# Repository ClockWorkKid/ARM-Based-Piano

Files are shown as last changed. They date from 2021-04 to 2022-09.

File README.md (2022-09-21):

# ARM-Based-Piano
STM32 based digital piano project for EEE416 Microprocessor and Embedded Systems Laboratory

Demonstration video <a href="https://youtu.be/l-ic4qlintA">link</a>

[](https://www.youtube.com/watch?v=l-ic4qlintA "Now in Android: 55")

## Contents
- [Repository Overview](#repository-overview)
- [Materials Used](#materials-used)
- [Softwares Used](#softwares-used)
- [Useful Links](#useful-links)
- [Working Procedure](#working-procedure)
- [Resampling Implementation in MATLAB](#resampling-implementation-in-matlab)
- [Resampling Implementation in C](#resampling-implementation-in-c)
- [DAC Simulation and Design Using Proteus](#dac-simulation-and-design-using-proteus)
- [Keyboard Interfacing Using Arduino DUE and Interrupt](#keyboard-interfacing-using-arduino-due-and-interrupt)
- [STM32 Code](#stm32-code)
- [Team](#team)

## Repository Overview
The repository directories include several folders for each component of the project. The purpose of each of the folders is listed here:

- **Solidworks Design** contains hardware design files that was used to build the PVC structure.
 
- **Arduino Due** folder contains the codes for the keyboard interfacing part of the piano. This board was used to read inputs from the 36 keys of the piano and send the keypress information to the STM32 board.

- **Matlab Simulation** folder contains resampling implementation and test codes for matlab. This was the first test for audio tone synthesis from a single note. Afterwards this code was ported to C.

- **C simulation** folder contains C-codes for audio resampling implementation which was directly used in the STM32 project code.

- **STM32** is the STM32CubeIDE project folder where the final implementation of SD-card reading, keyboard interfacing, audio synthesis and playback was implemented.

## Materials Used

- STM32F746 Discovery Board
- Arduino Due Board
- Arduino Uno Proto Shield
- Screws (for key contact + body)
- Female-Female jumpers (A lot!)
- 26 AWG wires (connects screws with circuit board)
- Aluminium foil (positive rail)
- 3.5mm headphone jack female
- Veroboard, soldering tools
- AWEI Y220 speaker with auxiliary cable
- Micro SD Card

## Softwares Used

- STM32CubeIDE
- Arduino IDE
- Proteus
- Matlab
- Codeblocks

## Useful Links

- <a href="https://www.youtube.com/playlist?list=PLc2rvfiptPSR0bzPjEsg5zmj0jvYMZLbV">A youtube playlist</a> containing useful videos for the STM32F746 Discovery Board

## Working Procedure

### Audio note synthesis from a single base note

A sample note of high resolution (44.1 KHz, 24 bit sample size) was downloaded. (The notes can be found at http://theremin.music.uiowa.edu/MISpiano.html). First we trimmed the note, and resampled it using MATLAB to see if the new note satisfies the frequency requirements of the target note. Then the resample function of MATLAB was manually written using resample theory (upsampling, interpolation using sinc function, downsampling). This code also generated similar notes, implying the correct operation of resample function. Finally the resampling function was ported to C code for using with STM32 board

<p align="center">
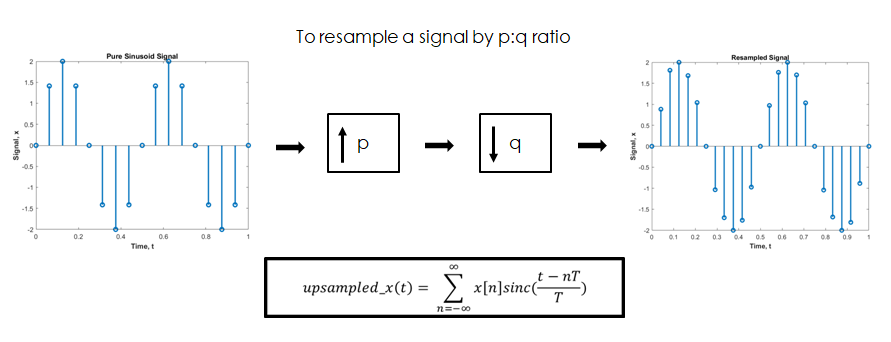
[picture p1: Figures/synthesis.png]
Note Synthesis
  
</p>

### Keyboard interfacing with a STM32 board

The designed hardware keyboard has 36 keys in total (3 octaves) and the keys are all connected to the Arduino DUE board (the STM32 discovery board did not have enough pins available as most of them were connected internally to other peripherals). Arduino DUE board reads the keypresses in polling mode with debouncing enabled. When a keypress is detected, DUE board sents an interrupt to the STM32 board along with the ID of the corresponding key being pressed.

### Note playback from STM32 board

The 36 piano notes are saved inside a micro SD card in binary format (8 kHz sampling rate, 8 bit resolution) and when a keypress is detected, the STM32 Discovery board reads the corresponding binary file, sends the audio samples to a buffer, and using the DAC circuit, these sample values are sent to the speaker device.

<p align="center">
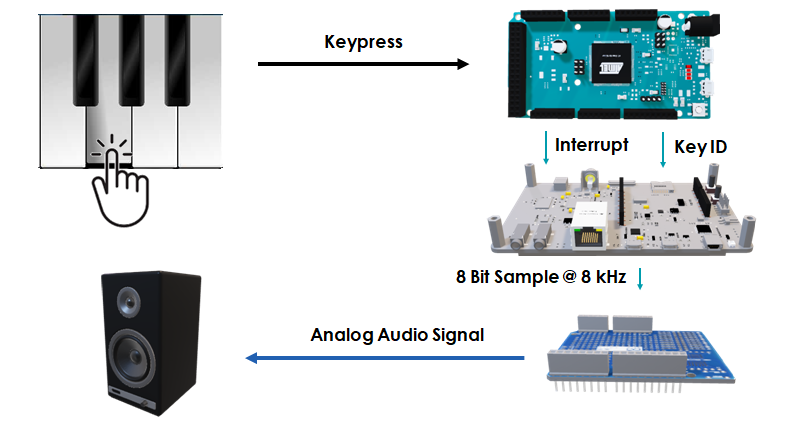
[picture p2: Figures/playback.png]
Note Playback
  
</p>

## Resampling Implementation in MATLAB
### Fundamentals:

In a conventional piano, there are 88 keys (A0-C8) that all produce tones of different frequency. These keys are divided into 8 octaves. Each octave has 12 steps.

An example of an octave is as follows: A0, A0#, B0, C1, C1#, D1, D1#, E1, F1, F1#, G1, G1#

Our task is to take one of these tones as our fundamental audio which we will then use to resample and generate the other audio tones of different frequencies.

In our project, we have decided to take A2 as our fundamental tone. It has a frequency of 110 Hz. Now, the other audio tones are related to the base frequency through the following equation:

f(n)=2^((n-25)/12)×110 Hz

Here, n represents the number of the piano key. The number of the piano keys are also predetermined. The lowest frequency tone A0 corresponds to key 1 and the highest frequency tone C8 corresponds to key 88. Our base audio A2 has key 25. Through the relation in equation (1), we can determine the resampling ratio that is needed to generate any particular tone from A2.

### Resampling on sinusoidal signal:

Before we move on to how resampling is performed on the raw audio, it is easier to demonstrate the theory of resampling using a short pure sinusoid signal. Let us assume, we have a pure sinusoid of frequency 2 Hz and it has been sampled at a rate of 16 Hz. So the sampled signal looks as the following:

<p align="center">
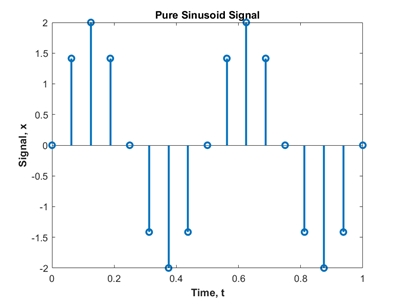
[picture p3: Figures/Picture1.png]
Sampled Signal
  
</p>

Our goal is to resample it at a ratio of 3:2. In order to do this, we need to,
Upsample the signal by 3. That means, (3-1) = 2 new samples will be inserted between every successive sample. Then downsample the signal by 2. That means, one sample is kept and the next is discarded.

### Upsampling

To Upsample the signal, we use the following equation of Sinc interpolation, 

<p align="center">
  
</p>

Here, x[n] is the original signal. It has a sampling period, T. We need to interpolate between two successive samples of ‘x’ and find out the extra sample values in between. The ‘t’ essentially represents the upsampled time axis. Now, we will visualize what’s happening with animation.

<p align="center">
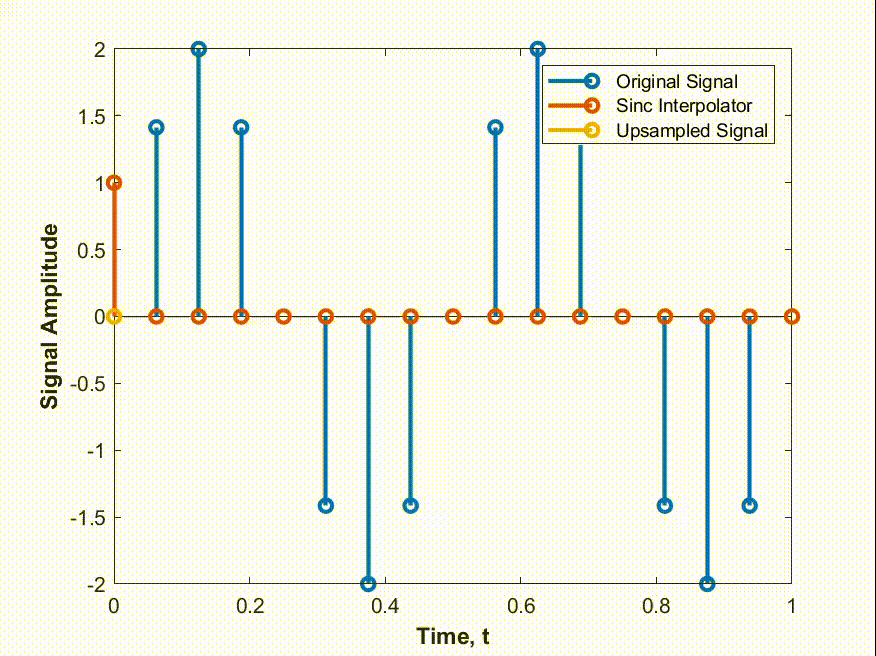
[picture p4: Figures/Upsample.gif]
Upsampled Signal
  
</p>

In this animation, the original signal is being upsampled by a factor of 3. So, 2 new samples are interpolated between any two successive samples. This interpolation is done through the use of a sinc function. As you can see, the sinc does a weighted averaging of the original signal at the new sampling instances. The amplitude of the upsampled signal at the original sampling instances remains the same as the sinc becomes zero everywhere else but the sampling instance.

#### Code Snippet: 

``` MATLAB
function [upsampled_x_raw, upsampled_t] = upsample(x,t,upsampling_factor)

T = t(2)-t(1);
fs = 1/T;

fs_upsample = upsampling_factor*fs;
upsampled_t = 0:1/fs_upsample:((length(x)-1)/fs);
upsampled_x_raw = zeros(length(upsampled_t), 1);

a = zeros(length(t),1);

for i = 1:length(upsampled_t)
    a(:,1) = upsampled_t(i);
    b = a - t';
    d = sinc(b/T);
    upsampled_x_raw(i) = sum(x'.*d);
end

end

```
### Downsampling: 
Downsampling refers to removing samples at a periodic interval from the upsampled signal. In the animation, we can see the that every alternate sample is being removed from the upsampled signal. The result is a signal downsampled by a factor of 2. 

<p align="center">
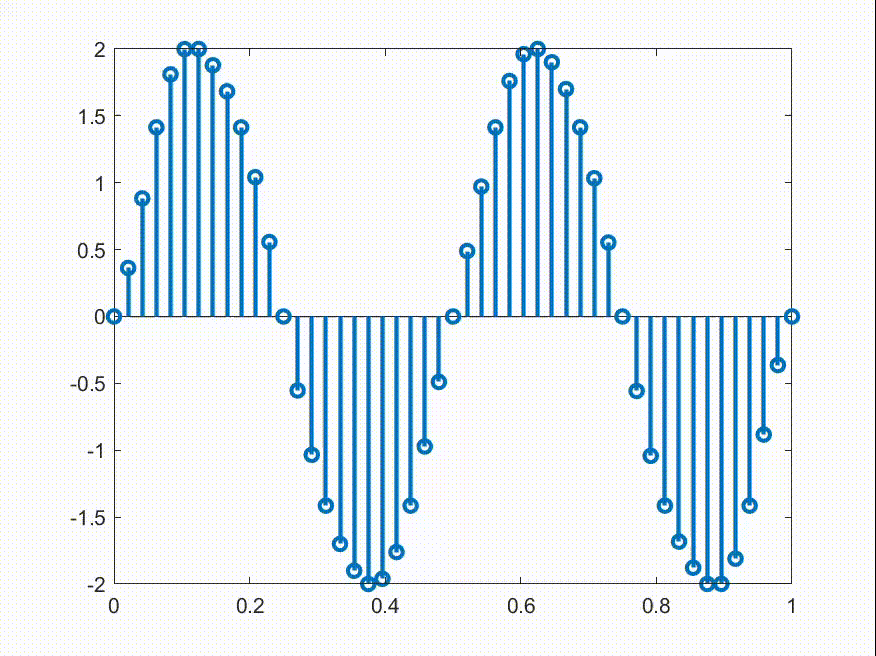
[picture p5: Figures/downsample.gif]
Downsampled Signal
  
</p>

#### Code Snippet:
``` C
function [downsampled_x, downsampled_t] = downsample(x,t,downsampling_factor)

T = t(2)-t(1);
fs = 1/T;

downsampled_x = zeros(round((1/downsampling_factor)*length(x)),1);
fs_downsample = fs/downsampling_factor;
downsampled_t = 0:1/fs_downsample:((length(x)-1)/fs);

for i=1:length(downsampled_x)
    downsampled_x(i) = x(i*downsampling_factor - downsampling_factor + 1);
end

end

```
### Main Code:
``` MATLAB
clear all, close all, clc

%% Load Audio
% http://theremin.music.uiowa.edu/MISpiano.html
[A2, fs] = audioread("Piano.pp.A2.aiff");
A2 = A2(1:100000, :)*10; 
t = 0:1/fs:((length(A2)-1)/fs);

%% Upsampling and filtering
upsampling_factor = 2;
[upsampled_A2, upsampled_t] = upsample(A2(:,1)',t,upsampling_factor);

%% Downsampling
downsampling_factor = 1;
[A1_M, downsampled_t] = downsample(upsampled_A2, upsampled_t, downsampling_factor);

```
## Resampling Implementation in C
Now that we have an understanding of how to implement resampling in software, we need to make our code hardware compatible. To do this, we rewrite the same functions in C. The underlying principles are the same, so we are only going to show the code snippets.
### Code Snippets:
#### Upsampling: 

``` C
void upsample()
{
    int k,j;
    double t_step,fs_u,b,sum;
    t_step = 1/fs;
    fs_u = fs*u;
    for(k=0; k<up_SIZE; k++)
    {
        b = (double)k/fs_u;
        sum = 0;
        for (j=0;j<SIZE;j++)
        {
          a[j] = (b/t_step) - j;
            if (a[j]!=0)           
                a[j] = sin(pi*a[j])/(pi*a[j]);
            else
                a[j] = 1;
            sum = sum + a[j]*x[j];
        }       up_x[k] = sum;
    }
}
```
#### Downsampling:
``` C
void downsample()
{
    int k;
    for(k = 0; k<down_SIZE; k++)
    {
        down_x[k] = up_x[d*k];
    }
}

```

However, there are some challenges in hardware implementation. These are listed as follows:
- Since any two consecutive audio tones are related to each other by a factor of 2^(1/12), so we have to approximate this irrational number to an integer ratio. But there are practical limitations on this ratio. Because we have limited memory on our microcontroller board, we cannot upsample the signal to any arbitrary ratio.
- Since our audio signal is large (64000 samples), we cannot perform resampling on the total signal at once because the upsampled signal becomes too large and does not fit into memory

### Solution to memory limitations:

The audio signal is broken up to equal sized slices. Resampling is performed on one slice at a time.

The signal slice after downsampling is then written to the external memory card

<p align="center">
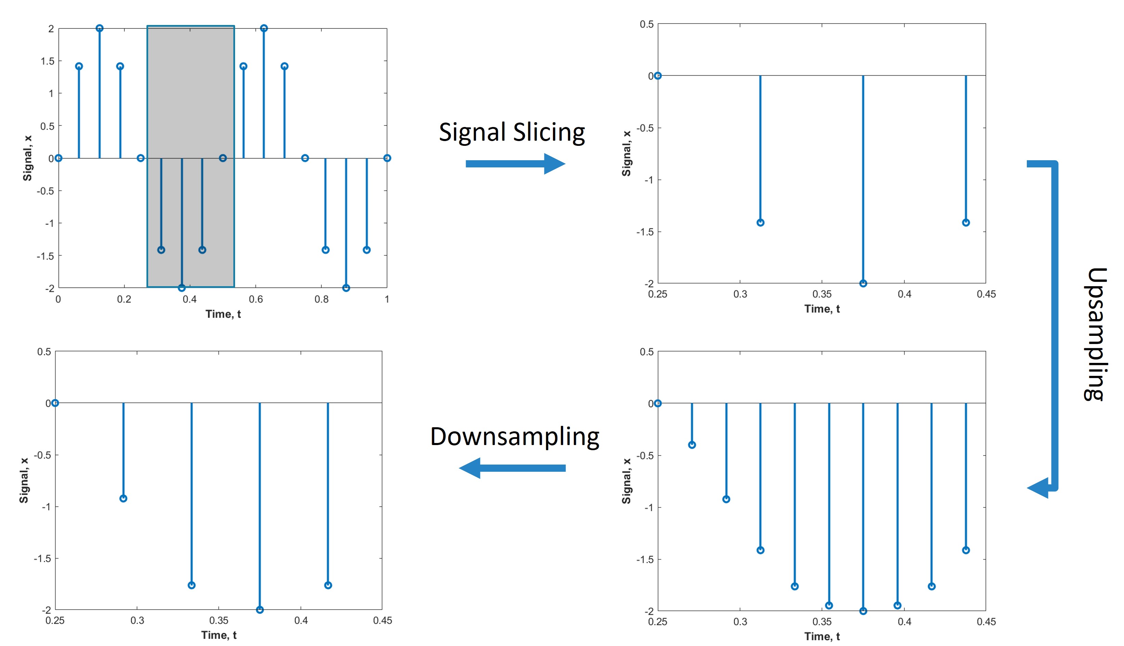
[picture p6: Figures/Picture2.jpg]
Resampling summary
  
</p>

#### Code Snippet for Signal Slicing:
``` C
for(i=0; i<num_iter; i++)
{
    /*get 1000 values and load into x*/
    for (j=0; j<SIZE; j++)
    {
       //convert integer to float
       float_value = (double)((DATA_BUFFER[i*SIZE + j] - 127));
       x[j] = float_value/128;
    }

    upsample();
    downsample();

    //convert to integer again
    for (j=0; j<down_SIZE; j++)
    {
      FINAL_BUFFER[j] = (uint8_t)(down_x[j]*128.0 + 127.0);
    }

}
```

### Parameters and Error Minimization:
- The highest Upsampling ratio we have used is 25. 
- The slice length is set to 800
There is a trade-off between these two parameters. If we increase the slice length, then the highest permissible ratio for Upsampling will decrease to meet memory requirements and vice-versa.
Between the end of any slice and the beginning of the next slice, the extra samples for Upsampling are not inserted. This is a source of error. Since we keeping the slice length to a sufficiently large number, this error is not significant.  

## Keyboard Interfacing Using Arduino DUE Interrupt

### Arduino DUE Connection with Keyboard Hardware

A hardware keyboard was prepared using 5mm PVC sheet. Each of the piano keys has a screw through them, and on the other side of each screw is a wire connecting it to a circuit board.
<p align="center">
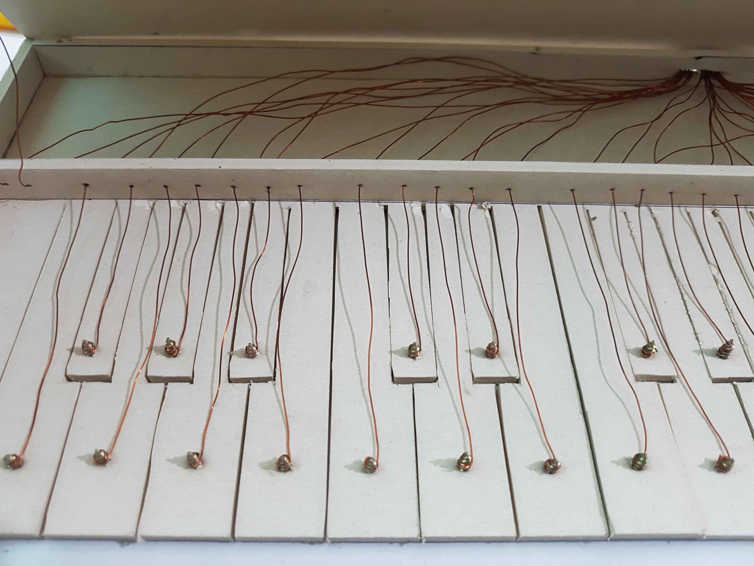
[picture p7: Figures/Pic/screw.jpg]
Key connections
  
</p>

These keys are pulled down with a 10k resistor each.
<p align="center">
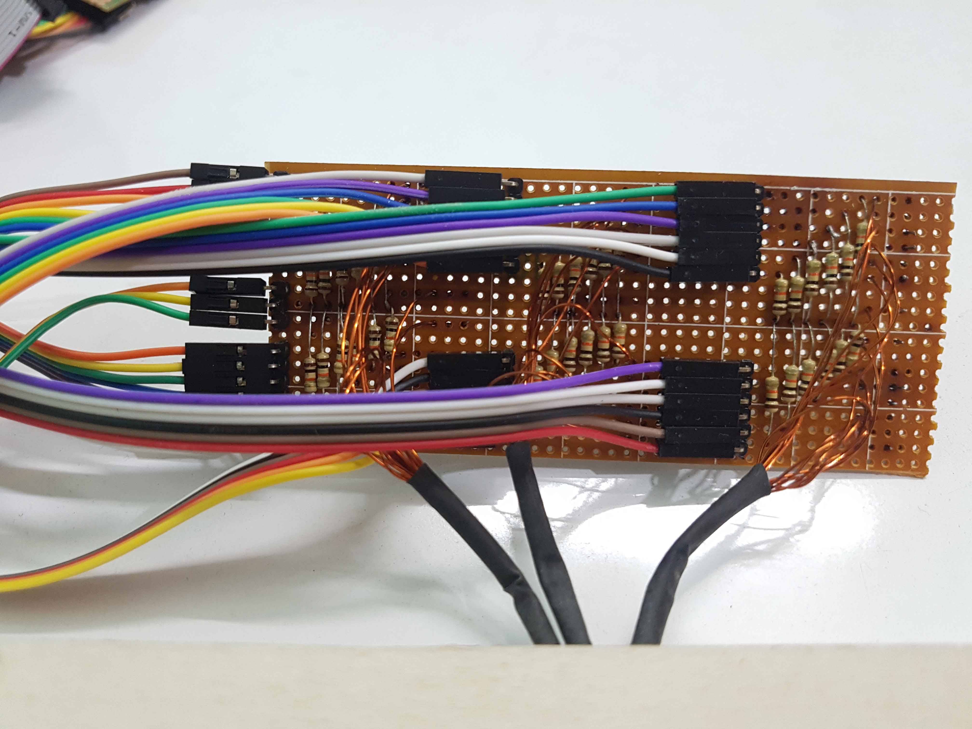
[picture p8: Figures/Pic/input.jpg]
Pulldown Circuit
  
</p>

The bottom panel of the keyboad has aluminium foil body connected to positive terminal of the circuit board.
<p align="center">
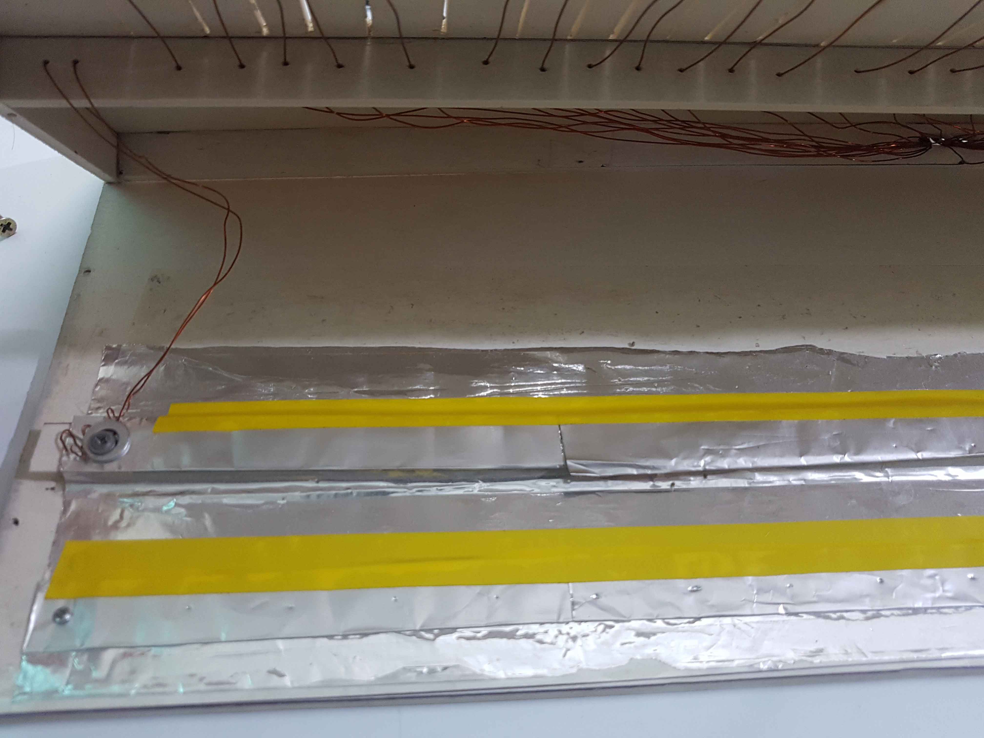
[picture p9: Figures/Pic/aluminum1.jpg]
Metal Plane
  
</p>

Each of the key wire is connected to Arduino DUE digital input pins.

<p align="center">
  Input Circuit
</p>

Arduino DUE reads the 36 keys in polling method. 
``` C Arduino
 for (int i = 0; i < 36; i++) {
    t0 = millis();
    if (t0 - debouncer[i] >= debounce_time) {
      reading = digitalRead(notes[i]);
      if (reading && !state[i]) {
        state[i] = 1;
        debouncer[i] = t0;
	 sendKey(i);
      	}
      else if (!reading && state[i]) {
        state[i] = 0;
        debouncer[i] = t0;
	}
    }
  }

```
### Arduino DUE Connection with STM32 Discovery Board
Upon detection of a keypress, DUE board generates an interrupt signal and a corresponding key ID signal. The DUE board is snapped onto the Arduino header pins of the STM32 Discovery board like a generic arduino shield.
<p align="center">
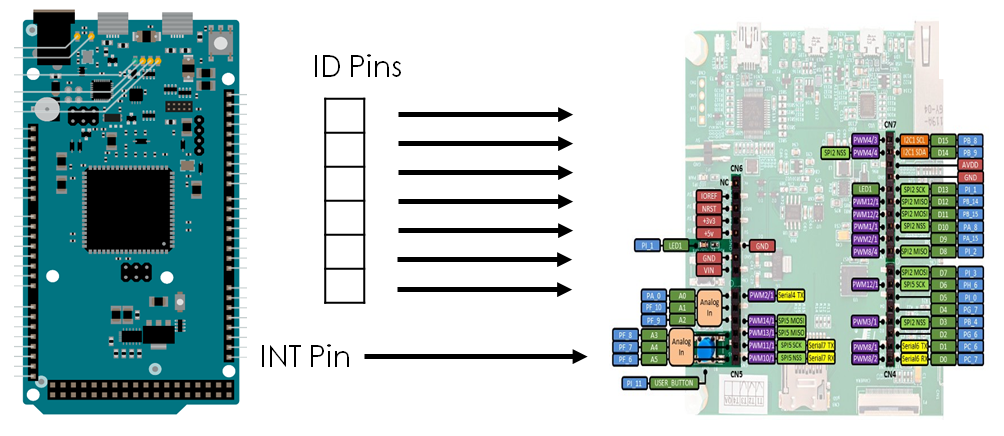
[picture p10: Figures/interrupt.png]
Interrupt Circuit
  
</p>

**Interrupt Generation from Arduino DUE**

```C Arduino
void sendKey(int pin){
  digitalWrite(INF[0], LOW);
  digitalWrite(IDP[0], !!(pin & 1<<0));
  digitalWrite(IDP[1], !!(pin & 1<<1));
  digitalWrite(IDP[2], !!(pin & 1<<2));
  digitalWrite(IDP[3], !!(pin & 1<<3));
  digitalWrite(IDP[4], !!(pin & 1<<4));
  digitalWrite(IDP[5], !!(pin & 1<<5));
  digitalWrite(INF[0], HIGH);
}
```

## DAC Simulation and Design Using Proteus
A simple R-2R resistor ladder DAC with 8 bit resolution was designed. This was built onto an Arduino Prototype Shield that could be easily stacked onto the STM32F7 Discovery board Arduino Compatible Headers.

<p align="center">
  DAC Circuit
</p>

## STM32 Code

The first task is to detect a keypress interrupt and identify the key being pressed. This information is sent by the Arduino DUE board.

**Interrupt Service Routine on STM32**

``` C
void keyboard_interrupt_handler(){
  key_ID[0] = HAL_GPIO_ReadPin(GPIOA, GPIO_PIN_0);
  key_ID[1] = HAL_GPIO_ReadPin(GPIOF, GPIO_PIN_10);
  key_ID[2] = HAL_GPIO_ReadPin(GPIOF, GPIO_PIN_9);
  key_ID[3] = HAL_GPIO_ReadPin(GPIOF, GPIO_PIN_8);
  key_ID[4] = HAL_GPIO_ReadPin(GPIOF, GPIO_PIN_7);
  key_ID[5] = HAL_GPIO_ReadPin(GPIOF, GPIO_PIN_6);

  keypress = (key_ID[5]<<5) + (key_ID[4]<<4) + (key_ID[3]<<3) + (key_ID[2]<<2) + (key_ID[1]<<1) + (key_ID[0]<<0);

  read_BIN_AUDIO(keypress);	// read the corresponding audio file from SD card and save to data buffer
  update_audio_buffer();		// add the tone to the audio buffer
}
```

Inside the micro sd card, audio files are saved in binary format, each of the audio sample is of 8 bit, represented in binary form. The samples are read directly without any form of compression/decompression. The audio samples are stored onto a buffer array. <a href="https://www.youtube.com/playlist?list=PLc2rvfiptPSR0bzPjEsg5zmj0jvYMZLbV">(Tutorial on SD card handling)</a>

**Reading audio from micro sd card**

``` C
void read_BIN_AUDIO(int note)
{
	res = f_open(&myFile, audio_filenames[note], FA_OPEN_ALWAYS|FA_WRITE|FA_READ);
	res = f_read(&myFile, DATA_BUFFER, BUFF_SIZE, &bytesRead);
	f_close(&myFile);
}
```

<p align="center">
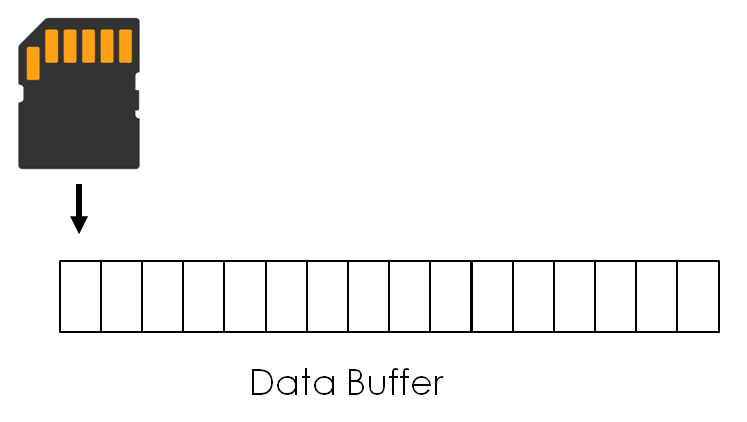
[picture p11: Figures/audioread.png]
Read SD Card
  
</p>

After reading the full audio file, the elements of the file buffer are copied over to the current position of the circular audio buffer.

``` C
void update_audio_buffer(){
	int idx_audio, idx_data;
	idx_audio = AUDIO_PTR + 1;	
	for (idx_data=0; idx_data<bytesRead; idx_data++){
		idx_audio = (idx_audio+1) % BUFF_SIZE;		
		AUDIO_BUFFER[idx_audio]= DATA_BUFFER[idx_data];
	}
}
```
A timer interrupt reads the audio buffer at a rate of 8kHz and outputs the audio samples via the DAC circuit.

**Timer interrupt**

``` C
void HAL_TIM_PeriodElapsedCallback(TIM_HandleTypeDef *htim)
{
	AUDIO_PTR = (AUDIO_PTR+1) % BUFF_SIZE;

	DAC_REG = AUDIO_BUFFER[AUDIO_PTR];
	AUDIO_BUFFER[AUDIO_PTR] = 127;		
	DAC_OUTPUT();
}
```

**DAC Signal Generation on STM32**

``` C
void DAC_OUTPUT(){
	HAL_GPIO_WritePin(GPIOI, GPIO_PIN_3, !!(DAC_REG & (1<<7)));
	HAL_GPIO_WritePin(GPIOH, GPIO_PIN_6, !!(DAC_REG & (1<<6)));
	HAL_GPIO_WritePin(GPIOI, GPIO_PIN_0, !!(DAC_REG & (1<<5)));
	HAL_GPIO_WritePin(GPIOG, GPIO_PIN_7, !!(DAC_REG & (1<<4)));
	HAL_GPIO_WritePin(GPIOB, GPIO_PIN_4, !!(DAC_REG & (1<<3)));
	HAL_GPIO_WritePin(GPIOG, GPIO_PIN_6, !!(DAC_REG & (1<<2)));
	HAL_GPIO_WritePin(GPIOC, GPIO_PIN_6, !!(DAC_REG & (1<<1)));
	HAL_GPIO_WritePin(GPIOC, GPIO_PIN_7, !!(DAC_REG & (1<<0)));
}
```

## Team

- Mir Sayeed Mohammad (github - https://github.com/ClockWorkKid)
- Shafin Bin Hamid (github - https://github.com/shafinbinhamid)
- Ramit Dutta (github - https://github.com/RamitDutta)
- Himaddri Roy (github - https://github.com/himu587)
- Sujoy Mondal (github - https://github.com/sujoy-mondal)

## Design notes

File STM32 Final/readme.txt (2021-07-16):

All changes are made inside read_BIN_Audio. Rest of the code is same as main.c inside STM32

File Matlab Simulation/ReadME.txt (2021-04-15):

1. Run the sampling_debug.m file
Purpose: Take a demo sinusoidal signal. Resample to the ratio of 3/2 using both manual code and resample(x,3,2).
Compare the two results.

Notice that the last 2 plots in the first figure are similar.
The last plot is using resample(x,3,2) and the second last one is after resampling manually.

In the other figure, the error between the two resamplings is plotted. Notice the max error is very minimal compared to signal strength(40 times).

2. Download this .mat file from the following link.  https://drive.google.com/file/d/1aShftX6F_bBfsbXH9KTqvyle7zYE3Wpy/view?usp=sharing 

Run the following command. 'save A1_base_A2'

This will load the base audio, A2 and the sampled audio(using manual resampling) A1 into the workspace. 

Go to the end of the 'all_freq_raw.m' file. Run the last two sections. 
The second last section will first resample A2 using resample(x,2,1). 
Then it will play A1 twice. First the one found using resample(x,2,1) and second the manual one. 
Notice if the two sounds are the same.

The last section will plot the error between the two resampling methods. First one is for channel 1, second one is for channel 2.

Additional Information:

1. Base audio has been cut down. The first 100000 are kept and the rest are discarded. The main tone is in that part. You can plot and see for yourself.
2. The two channels are upsampled and downsampled independently. 
3. The upsampling operation takes a lot of time if the upsampling factor is kept large. 
For example, for generating B1 from A2, I was using an upsampling_factor = 25, downsampling_factor = 7. And, it took almost 1.5 hours to finish the upsampling.
It also takes up a lot of space since upsampled A2 is essentially 25 times larger than A2. 

So, we have to:
a) Keep the fractions as small as possible
b) Keep the results saved as text file/mat file

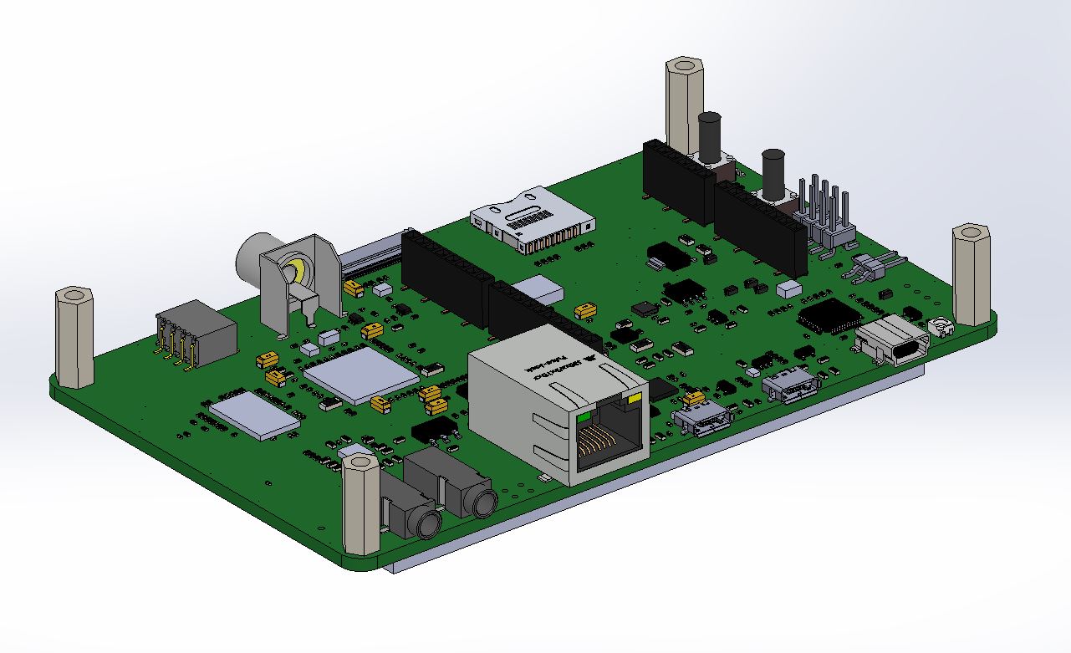
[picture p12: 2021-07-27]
Solidworks Design/stm32f7 disco1.JPG

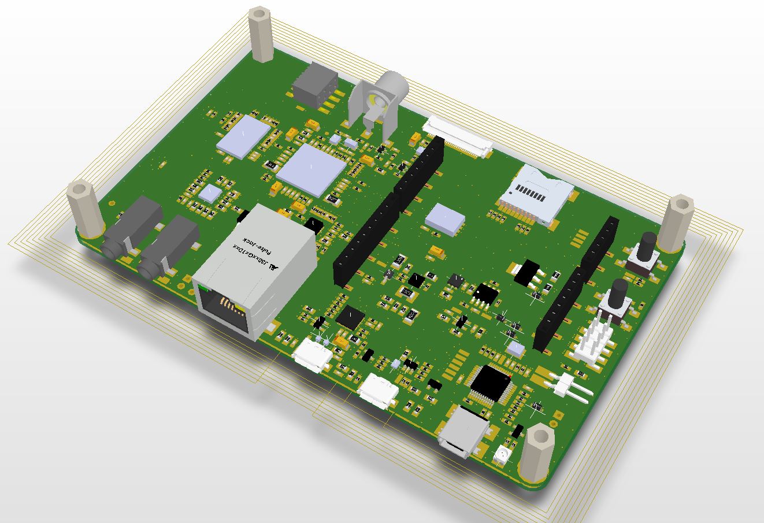
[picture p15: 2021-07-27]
Solidworks Design/stm32f7 disco.JPG

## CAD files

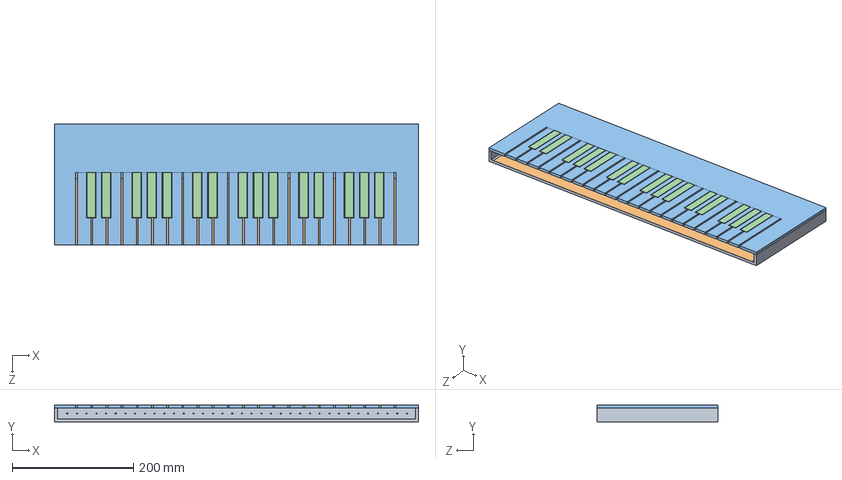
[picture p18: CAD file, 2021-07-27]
Solidworks Design/Piano_Body.SLDASM
600.0 x 27.6 x 200.0 mm
keyboard_base
metal
keyboard_top
sharp_key x 15

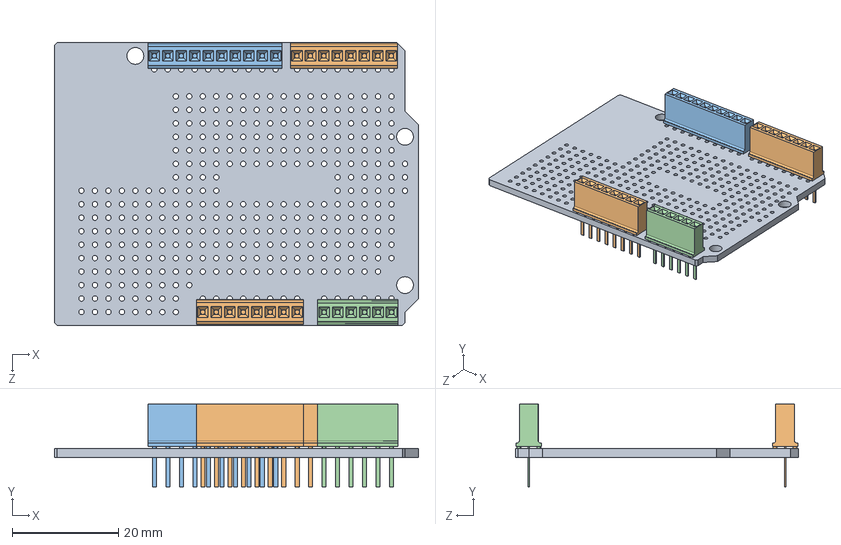
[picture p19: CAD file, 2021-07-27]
Solidworks Design/DAC_Shield.SLDASM
68.6 x 15.6 x 53.3 mm
Arduino proto shield R3
Berg Header Receptacle long x 2
Berg Header Receptacle 2.54 x 10 - FCI - 66951-010LF
Berg Header Receptacle 6

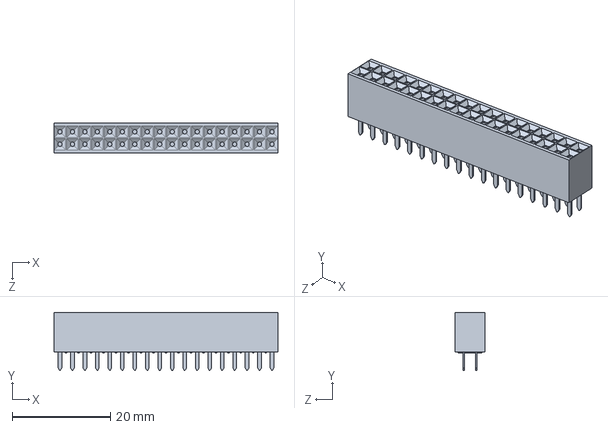
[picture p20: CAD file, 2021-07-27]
Solidworks Design/Arduino Due/Berg Header Receptacle 2.54 x 36 - FCI - 66953-018LF.SLDPRT
45.6 x 11.8 x 6.10 mm

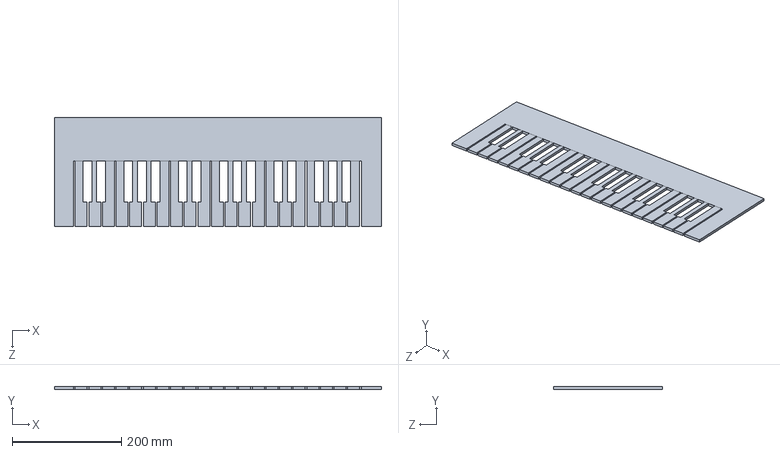
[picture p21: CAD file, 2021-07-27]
Solidworks Design/keyboard_top.SLDPRT
600.0 x 5.10 x 200.0 mm

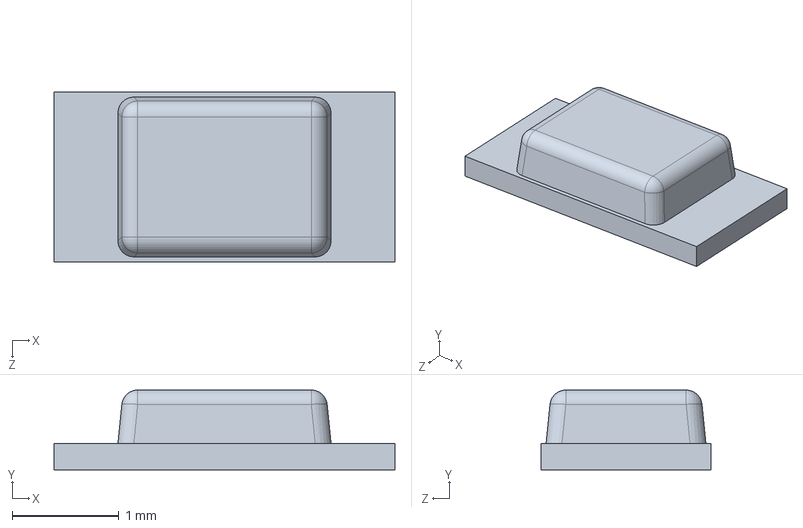
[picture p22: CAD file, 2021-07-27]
Solidworks Design/Arduino Due/LED - Kingbright - KPT-3216EC.SLDPRT
3.20 x 0.75 x 1.60 mm

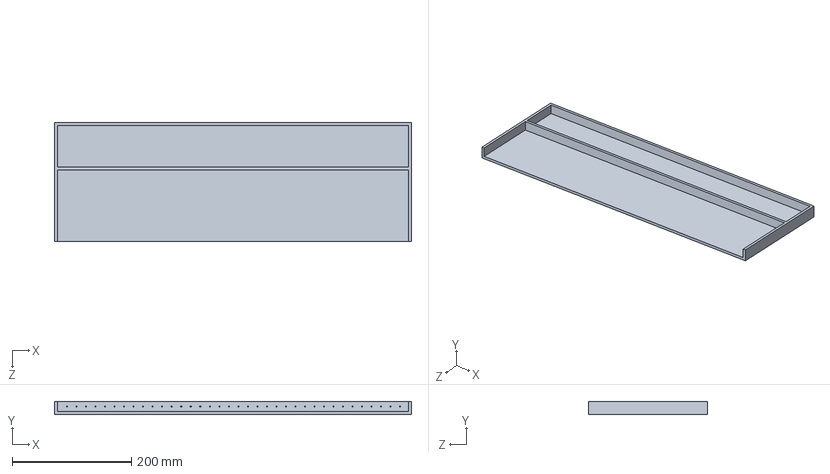
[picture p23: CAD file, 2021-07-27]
Solidworks Design/keyboard_base.SLDPRT
600.0 x 22.5 x 200.0 mm

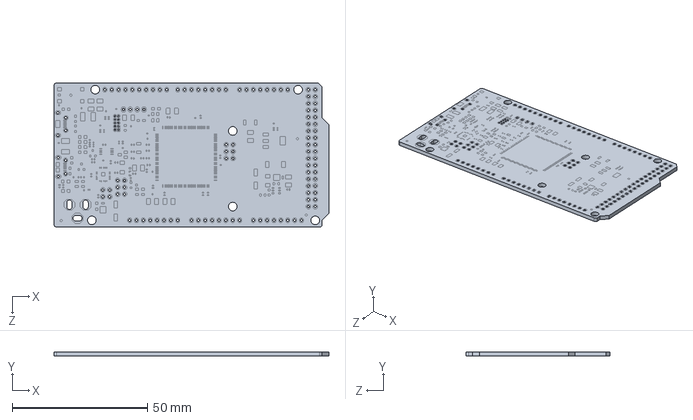
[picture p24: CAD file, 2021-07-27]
Solidworks Design/Arduino Due/PCB - Arduino.SLDPRT
101.6 x 1.62 x 53.3 mm

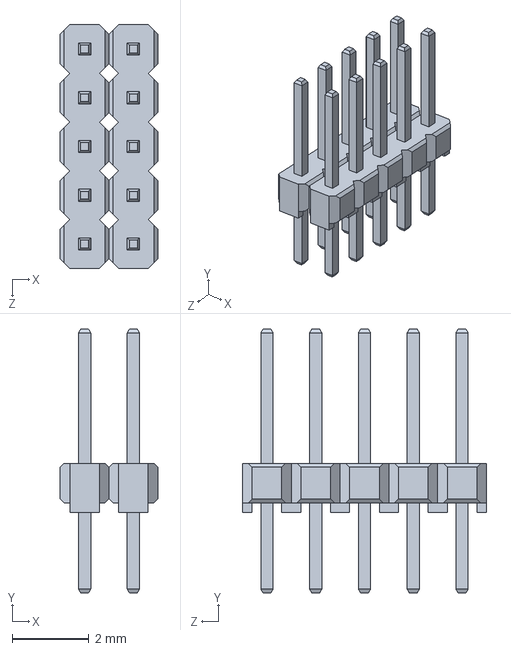
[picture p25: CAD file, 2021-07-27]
Solidworks Design/Arduino Due/Berg Header - 1.27 x 10.SLDPRT
2.54 x 6.88 x 6.35 mm

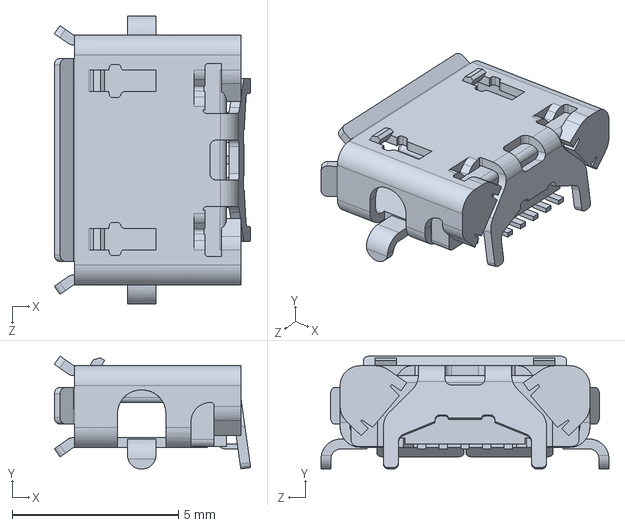
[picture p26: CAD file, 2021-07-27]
Solidworks Design/Arduino Due/MicroUSB AB - Hirose - ZX62D-AB-5P8.SLDPRT
5.90 x 3.39 x 8.65 mm

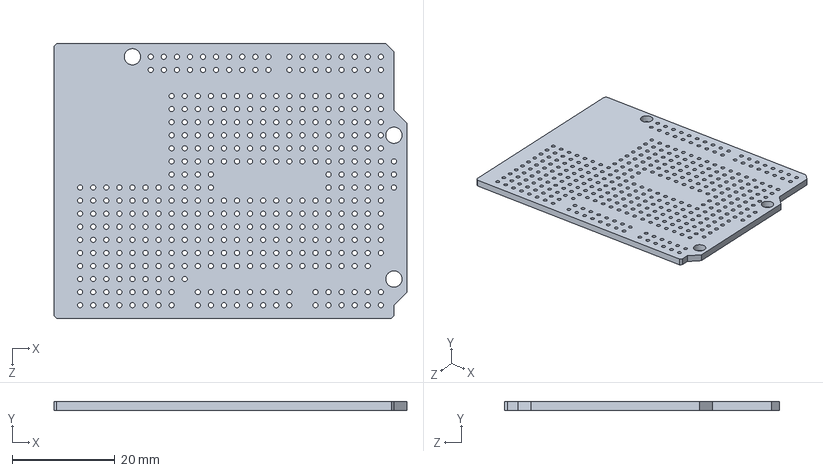
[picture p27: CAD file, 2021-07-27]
Solidworks Design/Arduino proto shield R3.SLDPRT
68.6 x 1.70 x 53.3 mm

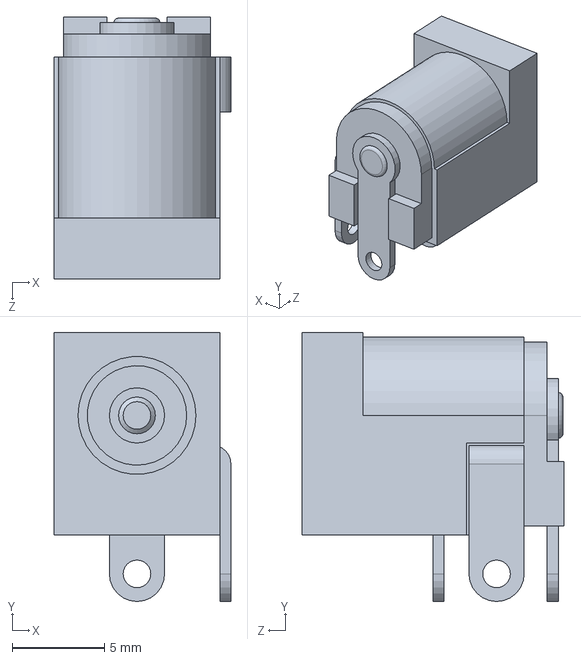
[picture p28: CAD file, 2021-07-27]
Solidworks Design/Arduino Due/Power Jack - Kycon - KLDHCX-0202-A.SLDPRT
9.60 x 14.6 x 14.2 mm

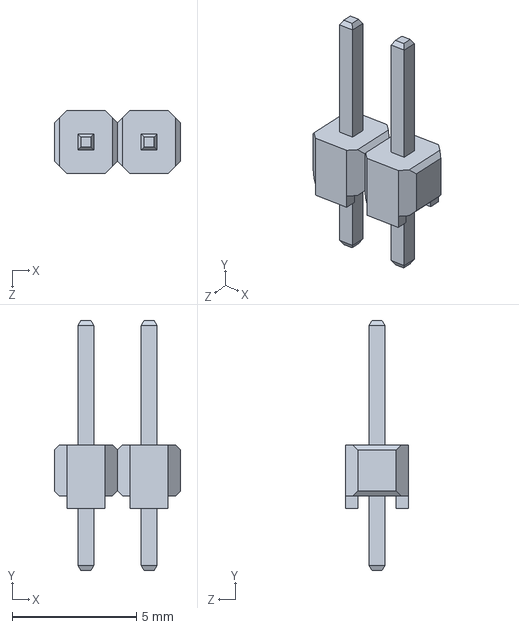
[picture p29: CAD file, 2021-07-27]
Solidworks Design/Arduino Due/Berg Header - 2.54 x 2.SLDPRT
5.08 x 10.0 x 2.54 mm

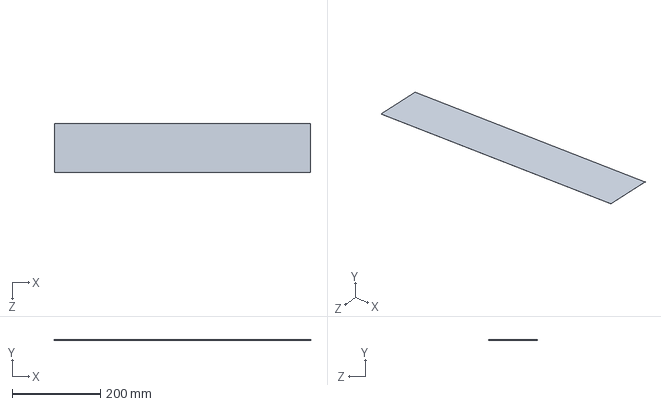
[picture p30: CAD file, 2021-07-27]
Solidworks Design/metal.SLDPRT
580.0 x 0.1 x 110.0 mm

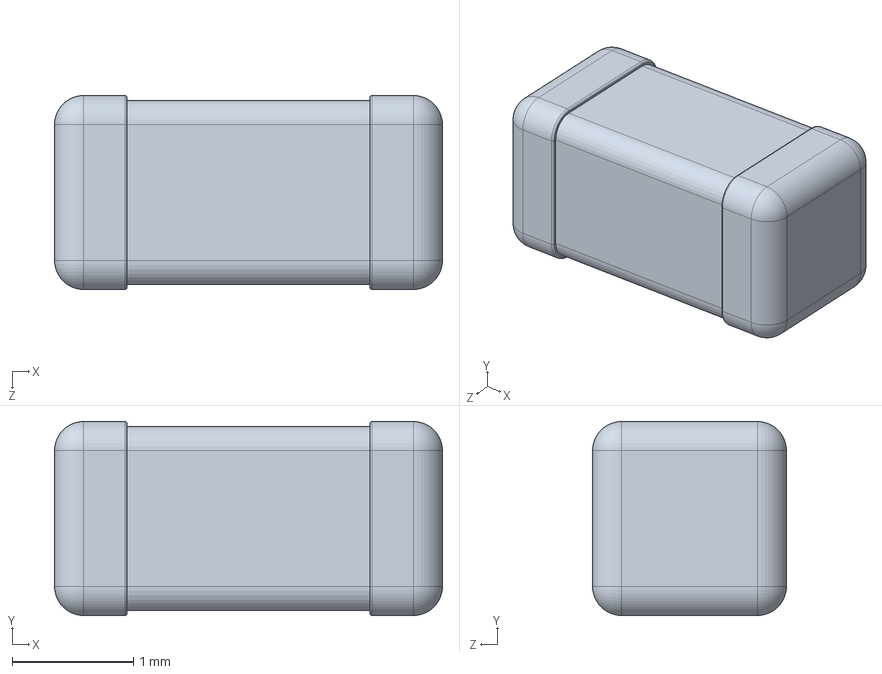
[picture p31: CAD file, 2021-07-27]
Solidworks Design/Arduino Due/Capacitor.SLDPRT
3.20 x 1.60 x 1.60 mm

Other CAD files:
Solidworks Design/sharp_key.SLDPRT
Solidworks Design/Arduino Due/Switch - ESwitch - TLE3303.SLDPRT
Solidworks Design/Arduino Due/Berg Header Receptacle long.SLDPRT
Solidworks Design/Arduino Due/Berg Header Receptacle 2.54 x 10 - FCI - 66951-010LF.SLDPRT
Solidworks Design/Arduino Due/Berg Header Receptacle 2.54 x 8 - FCI - 66951-008LF.SLDPRT
Solidworks Design/Arduino Due/Berg Header Receptacle 6.SLDPRT
Solidworks Design/Arduino Due/Capacitor - Nichicon - UUR1C101MCL1GS.SLDPRT
Solidworks Design/Arduino Due/MicroUSB AB - Hirose - ZX62-AB-5PA.SLDPRT
Solidworks Design/Arduino Due/MicroUSB B - Hirose - ZX62D-B-5P8.SLDPRT
Solidworks Design/Arduino Due/Microchip - Atmel - SAM3X8EAU.SLDPRT

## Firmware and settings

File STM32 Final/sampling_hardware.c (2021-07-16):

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
/* Includes ------------------------------------------------------------------*/
#include "main.h"
#include "fatfs.h"

/* USER CODE BEGIN Includes */
#include "math.h"
/* USER CODE END Includes */

/* USER CODE BEGIN PM */

#define pi 3.1415926535

/* USER CODE END PM */


SD_HandleTypeDef hsd1;

TIM_HandleTypeDef htim2;

UART_HandleTypeDef huart1;

/* USER CODE BEGIN PV */

/*************************** SD CARD FILE OPERATION VARIABLES ****************************/

#define BUFF_SIZE  64000

FRESULT res;						// status variable for file operations
FATFS SDFatFs;						// file system mount variable
FIL myFile;							// file handle
uint8_t DATA_BUFFER[BUFF_SIZE];		// temporary data buffer to store file data
uint8_t AUDIO_BUFFER[BUFF_SIZE];	// circular audio buffer continuously playing audio

int AUDIO_PTR;						// pointer for audio buffer

unsigned int bytesRead;				// number of bytes that was read from a file

enum _bool{
	false=0,
	true=1
};
typedef enum _bool boolean;			// declared a boolean data type

char audio_filenames[36][8] = 		// filenames for binary audio files
{
	"C3.bin","C3s.bin","D3.bin","D3s.bin","E3.bin","F3.bin","F3s.bin","G3.bin","G3s.bin","A3.bin","A3s.bin","B3.bin",
	"C4.bin","C4s.bin","D4.bin","D4s.bin","E4.bin","F4.bin","F4s.bin","G4.bin","G4s.bin","A4.bin","A4s.bin","B4.bin",
	"c5.bin","C5s.bin","D5.bin","D5s.bin","E5.bin","F5.bin","F5s.bin","G5.bin","G5s.bin","A5.bin","A5s.bin","B5.bin"
};

/***************************** KEYBOARD PERPHERAL VARIABLES ******************************/

uint8_t DAC_REG;					// DAC register containing 8 bit audio samples to be output

uint32_t Fs = 8000;					// sampling frequency for note play-back

uint8_t key_ID[6], key_info[6];		// key_ID reads from Arduino DUE which key is pressed/released
									// key_info reads from Arduino DUE whether a key is pressed/released
uint8_t keypress;

float base_frequencies[36] =		// core audio tone frequencies starting from C3-B5
{130.81, 138.59, 146.83, 155.56, 164.81, 174.61, 185.00, 196.00, 207.65, 220.00, 233.08, 246.94,
 261.63, 277.18, 293.66, 311.13, 329.63, 349.23, 369.99, 392.00, 415.30, 440.00, 466.16, 493.88,
 523.25, 554.37, 587.33, 622.25, 659.25, 698.46, 739.99, 783.99, 830.61, 880.00, 932.33, 987.77};

/* USER CODE END PV */

void SystemClock_Config(void);
static void MX_GPIO_Init(void);
static void MX_TIM2_Init(void);
static void MX_USART1_UART_Init(void);
static void MX_SDMMC1_SD_Init(void);
/* USER CODE BEGIN 0 */

/******************************* SD CARD HANDLER FUNCTIONS *********************************/

void init_SD()
{
	res = BSP_SD_Init();				// initialize SD stuff
	res = f_mount(&SDFatFs, "", 1);		// mount the SD card
}

void read_BIN_AUDIO(int note)
{
	//res = f_open(&myFile, "c5.bin", FA_OPEN_ALWAYS|FA_WRITE|FA_READ);
	res = f_open(&myFile, audio_filenames[note], FA_OPEN_ALWAYS|FA_WRITE|FA_READ);
	res = f_read(&myFile, DATA_BUFFER, BUFF_SIZE, &bytesRead);

	//the audio has been read and stored into DATA_BUFFER at this point
	//size of DATA_BUFFER is 64000
	//1000 values will be read during one iteration
	//resampling will be performed on these 1000 values
	//the resampled values will be appended to a text file

	//sampling ratios for different frequencies are saved in 'sampling_ratio.txt' file
	//insert the ratios at lines 139, 140

	//parameter declarations
	int SIZE = 1000;
	double fs = 44100;
    int u = 25; //upsampling ratio, make changes here
    int d = 28; //downsampling ratio, make changes here
    int up_SIZE = SIZE*u - u + 1; //audio size after upsampling
    int down_SIZE = (int)ceil((double)up_SIZE/d); //final size of audio

    double x[SIZE];
	double t[SIZE];
	double up_x[up_SIZE];
	double up_t[up_SIZE];
	double down_x[down_SIZE];
	double down_t[down_SIZE];

	uint8_t FINAL_BUFFER[down_SIZE];

	int num_iter = full_SIZE/SIZE;
    int i,j;
    int p;
    double float_value;

    //define a file handler for writing to a text file
    //FILE *fpw = fopen("B2_C.txt", "w");

    for(i=0; i<num_iter; i++)
    {
        /*get 1000 values and load into x*/
        for (j=0; j<SIZE; j++)
        {
            //convert integer to float
           float_value = (double)((DATA_BUFFER[i*SIZE + j] - 128));
           x[j] = float_value/128;
        }

        /*define t for these 1000 values*/
        for(p=0;p<SIZE;p++)
        {
            t[p] = p*( ((double)1) / fs);
        }

        //upsample
        upsample(x, t, up_x, up_t, u, up_SIZE);

        //downsample
        downsample(up_x, up_t, down_x, down_t, d, down_SIZE);

        //convert to integer again
        for (j=0; j<down_SIZE; j++)
        {
            //convert float to integer
           FINAL_BUFFER[j] = (uint8_t)(down_x[j]*128 + 128);
        }

        //append resampled values to file

    }

	f_close(&myFile);
}

void upsample(double *x, double *t, double *x_u, double *t_u, int u, int up_SIZE)
{
    int k,j;
    double t_step;
    double fs;
    double fs_u;

    t_step = t[1]-t[0];
    fs = 1/t_step;
    fs_u = fs*u;

    double a[SIZE];
    double sum;

    for(k=0; k<up_SIZE; k++)
    {
        t_u[k] = (double)k/fs_u;
        sum = 0;
        for (j=0;j<SIZE;j++)
        {
            a[j] = (t_u[k] - t[j])/t_step;

            if (a[j]!=0)
            {
                a[j] = sin(pi*a[j])/(pi*a[j]);
            }
            else
            {
                a[j] = 1;
            }
            sum = sum + a[j]*x[j];
        }

        x_u[k] = sum;
    }

}

void downsample(double *x, double *t, double *x_d, double *t_d, int d, int down_SIZE)
{
    int k;
    for(k = 0; k<down_SIZE; k++)
    {
        x_d[k] = x[d*k];
        t_d[k] = t[d*k];
    }
}

void umount_SD()
{
	f_mount(0, "", 1);					// unmount the SD card
}

/***************************** KEYBOARD PERPHERAL FUNCTIONS ******************************/
/*
ARDUINO HEADERS ON STM32F746 DISCOVERY BOARD (used for 8 bit DAC)
pin7	PI3
pin6	PH6
pin5	PI0
pin4	PG7
pin3	PB4
pin2	PG6
pin1	PC6
pin0	PC7
*/

// this function reads DAC_REG and generates corresponding DC voltage level to the DAC
void DAC_OUTPUT(){
	HAL_GPIO_WritePin(GPIOI, GPIO_PIN_3, !!(DAC_REG & (1<<7)));
	HAL_GPIO_WritePin(GPIOH, GPIO_PIN_6, !!(DAC_REG & (1<<6)));
	HAL_GPIO_WritePin(GPIOI, GPIO_PIN_0, !!(DAC_REG & (1<<5)));
	HAL_GPIO_WritePin(GPIOG, GPIO_PIN_7, !!(DAC_REG & (1<<4)));
	HAL_GPIO_WritePin(GPIOB, GPIO_PIN_4, !!(DAC_REG & (1<<3)));
	HAL_GPIO_WritePin(GPIOG, GPIO_PIN_6, !!(DAC_REG & (1<<2)));
	HAL_GPIO_WritePin(GPIOC, GPIO_PIN_6, !!(DAC_REG & (1<<1)));
	HAL_GPIO_WritePin(GPIOC, GPIO_PIN_7, !!(DAC_REG & (1<<0)));
}

// starts at the current audio_pointer location and from there keeps adding values of data
// buffer to audio buffer for new tone.
void update_audio_buffer(){
	int idx_audio, idx_data;
	// int scaling_factor = 2;		// scaling factor to make sure value does not overflow
	idx_audio = AUDIO_PTR + 1;	// get current position of audio buffer pointer
	for (idx_data=0; idx_data<bytesRead; idx_data++){
		idx_audio = (idx_audio+1) % BUFF_SIZE;
		AUDIO_BUFFER[idx_audio]+=AUDIO_BUFFER[idx_audio] + DATA_BUFFER[idx_data];
	}
}

/*
Key ID data Pins	Information Pins
IDP[0] A0 PA0		INF[0] pin8 PI2
IDP[1] A1 PF10		INF[1] pin9 PA15
IDP[2] A2 PF9		INF[2] pin10 PA8
IDP[3] A3 PF8		INF[3] pin11 PB15
IDP[4] A4 PF7		INF[4] pin12 PB14
IDP[5] A5 PF6		INF[5] pin13 PI1
*/
// reads key press/release information from Arduino DUE
void keyboard_interrupt_handler(){
	key_ID[0] = HAL_GPIO_ReadPin(GPIOA, GPIO_PIN_0);
	key_ID[1] = HAL_GPIO_ReadPin(GPIOF, GPIO_PIN_10);
	key_ID[2] = HAL_GPIO_ReadPin(GPIOF, GPIO_PIN_9);
	key_ID[3] = HAL_GPIO_ReadPin(GPIOF, GPIO_PIN_8);
	key_ID[4] = HAL_GPIO_ReadPin(GPIOF, GPIO_PIN_7);
	key_ID[5] = HAL_GPIO_ReadPin(GPIOF, GPIO_PIN_6);

	keypress = (key_ID[5]<<5) + (key_ID[4]<<4) + (key_ID[3]<<3) + (key_ID[2]<<2) + (key_ID[1]<<1) + (key_ID[0]<<0);

//	key_info[0] = HAL_GPIO_ReadPin(GPIOI, GPIO_PIN_2);		// interrupt
//	key_info[1] = HAL_GPIO_ReadPin(GPIOA, GPIO_PIN_15);
//	key_info[2] = HAL_GPIO_ReadPin(GPIOA, GPIO_PIN_8);
//	key_info[3] = HAL_GPIO_ReadPin(GPIOB, GPIO_PIN_15);
//	key_info[4] = HAL_GPIO_ReadPin(GPIOB, GPIO_PIN_14);
//	key_info[5] = HAL_GPIO_ReadPin(GPIOI, GPIO_PIN_1);

	read_BIN_AUDIO(keypress);	// read the corresponding audio file from SD card and save to data buffer
	update_audio_buffer();		// add the tone to the audio buffer

}


/******************************* AUDIO HANDLER FUNCTIONS *********************************/

// initializing the audio buffer to all values = 127 (mid value of DAC)
void init_audio_buffer()
{
	int idx;
	for (idx=0; idx<BUFF_SIZE; idx++){
		AUDIO_BUFFER[idx] = 127;
	}
}

// Timer interrupt service routine, regularly reads a value from the audio
// buffer at the sampling frequency and outputs the sample via DAC
void HAL_TIM_PeriodElapsedCallback(TIM_HandleTypeDef *htim)
{
	AUDIO_PTR = (AUDIO_PTR+1) % BUFF_SIZE;

	DAC_REG = AUDIO_BUFFER[AUDIO_PTR];
	AUDIO_BUFFER[AUDIO_PTR] = 127;		// after reading a sample, reset it

	DAC_OUTPUT();
}


/* USER CODE END 0 */

/**
  * @brief  The application entry point.
  * @retval int
  */
int main(void)
{
  /* Enable I-Cache---------------------------------------------------------*/
  SCB_EnableICache();

  /* Enable D-Cache---------------------------------------------------------*/
  SCB_EnableDCache();

  /* MCU Configuration--------------------------------------------------------*/

  /* Reset of all peripherals, Initializes the Flash interface and the Systick. */
  HAL_Init();

  /* Configure the system clock */
  SystemClock_Config();

  /* Initialize all configured peripherals */
  MX_GPIO_Init();
  MX_TIM2_Init();
  MX_USART1_UART_Init();
  MX_SDMMC1_SD_Init();
  MX_FATFS_Init();
  /* USER CODE BEGIN 2 */

  init_audio_buffer();

  init_SD();
  // read_BIN_AUDIO(0);
  // umount_SD();

  HAL_TIM_Base_Start_IT(&htim2);	// initialize timer counter interrupt for audio sample rate

  /* USER CODE END 2 */

  /* Infinite loop */
  /* USER CODE BEGIN WHILE */
  while (1)
  {
    /* USER CODE END WHILE */

    /* USER CODE BEGIN 3 */
	  //keyboard_update();			// reads the keyboard input infinitely

  }
  /* USER CODE END 3 */
}

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


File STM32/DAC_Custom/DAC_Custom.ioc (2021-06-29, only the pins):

PG6.Signal=GPIO_Output
Mcu.UserName=STM32F746NGHx
PC12.Signal=SDMMC1_CK
PA0/WKUP.Signal=GPIO_Input
PB15.Signal=GPIO_Input
PF7.Signal=GPIO_Input
PB6.Signal=USART1_TX
PC7.Signal=GPIO_Output
PH1/OSC_OUT.Signal=RCC_OSC_OUT
PI0.Signal=GPIO_Output
PI3.Signal=GPIO_Output
PB7.Signal=USART1_RX
PA8.Signal=GPIO_Input
PA15.Signal=GPIO_Input
PF8.Signal=GPIO_Input
PB4.Signal=GPIO_Output
PG7.Signal=GPIO_Output
PC8.Signal=SDMMC1_D0
PC6.Signal=GPIO_Output
PA13.Signal=SYS_JTMS-SWDIO
PF6.Signal=GPIO_Input
PB14.Signal=GPIO_Input
PH0/OSC_IN.Signal=RCC_OSC_IN
PF10.Signal=GPIO_Input
PI1.Signal=GPIO_Input
PI2.Signal=GPXTI2
PA14.Signal=SYS_JTCK-SWCLK
PH6.Signal=GPIO_Output
PF9.Signal=GPIO_Input
PD2.Signal=SDMMC1_CMD

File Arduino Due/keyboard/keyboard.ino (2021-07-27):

#define C0 53
#define CS0 51
#define D0 49
#define DS0 47
#define E0 45
#define F0 43
#define FS0 41
#define G0 39
#define GS0 37
#define A0 35
#define AS0 33  // not working
#define B0 31

#define C1 52
#define CS1 50
#define D1 48
#define DS1 46
#define E1 44
#define F1 42
#define FS1 40
#define G1 38
#define GS1 36
#define A1 34
#define AS1 32
#define B1 30

#define C2 14
#define CS2 15
#define D2 16
#define DS2 17
#define E2 18
#define F2 19
#define FS2 28
#define G2 26
#define GS2 24
#define A2 29 // not working
#define AS2 27
#define B2 25

int notes[36] = {C0, CS0, D0, DS0, E0, F0, FS0, G0, GS0, A0, AS0, B0, C1, CS1, D1, DS1, E1, F1, FS1, G1, GS1, A1, AS1, B1, C2, CS2, D2, DS2, E2, F2, FS2, G2, GS2, A2, AS2, B2};
int state[36], reading;

int IDP[6] = {54, 55, 56, 57, 58, 59};  // key ID pins
int INF[6] = {8, 9, 10, 11, 12, 13};    // information pins

unsigned long int debouncer[36], t0, t1;
unsigned long int debounce_time = 100;  // 100ms debouncing period

void sendKey(int pin){
  digitalWrite(INF[0], LOW);
  
  digitalWrite(IDP[0], !!(pin & 1<<0));
  digitalWrite(IDP[1], !!(pin & 1<<1));
  digitalWrite(IDP[2], !!(pin & 1<<2));
  digitalWrite(IDP[3], !!(pin & 1<<3));
  digitalWrite(IDP[4], !!(pin & 1<<4));
  digitalWrite(IDP[5], !!(pin & 1<<5));
  
  digitalWrite(INF[0], HIGH);           // positive edge triggered interrupt on stm32
}


void setup() {
  t0 = millis();
  for (int i = 0; i < 36; i++) {
    pinMode(notes[i], INPUT);
    debouncer[i] = t0;
  }

  for (int i = 0; i < 6; i++) {
    pinMode(IDP[i], OUTPUT);
    pinMode(INF[i], OUTPUT);
    digitalWrite(IDP[i], 0);
    digitalWrite(INF[i], 0);
  }
//
  Serial.begin(115200);
}

void loop() {
  for (int i = 0; i < 36; i++) {
    t0 = millis();
    if (t0 - debouncer[i] >= debounce_time) {
      reading = digitalRead(notes[i]);
      // key pressed
      if (reading && !state[i]) {
        state[i] = 1;
        debouncer[i] = t0;
        //Serial.print("Pressed ");
        //Serial.println(i);
        sendKey(i);
      }
      // key released
      else if (!reading && state[i]) {
        state[i] = 0;
        debouncer[i] = t0;
        //Serial.print("Released ");
        //Serial.println(i);
      }
    }
  }
}

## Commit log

2021-04-10 Added work on arduino and proteus
2021-04-29 STM32F103C simulation proteus
2021-06-04 STM32F746 Discovery working custom DAC
2021-07-27 Added solidworks design files
    [ARDUINO DUE.SLDASM, Arduino proto shield R3.SLDPRT, Berg Header - 1.27 x 10.SLDPRT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]
2021-10-17 stm32 description complete

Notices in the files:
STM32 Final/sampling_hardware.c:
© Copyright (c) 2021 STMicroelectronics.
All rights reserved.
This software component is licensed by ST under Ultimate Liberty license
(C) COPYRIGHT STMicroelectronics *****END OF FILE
